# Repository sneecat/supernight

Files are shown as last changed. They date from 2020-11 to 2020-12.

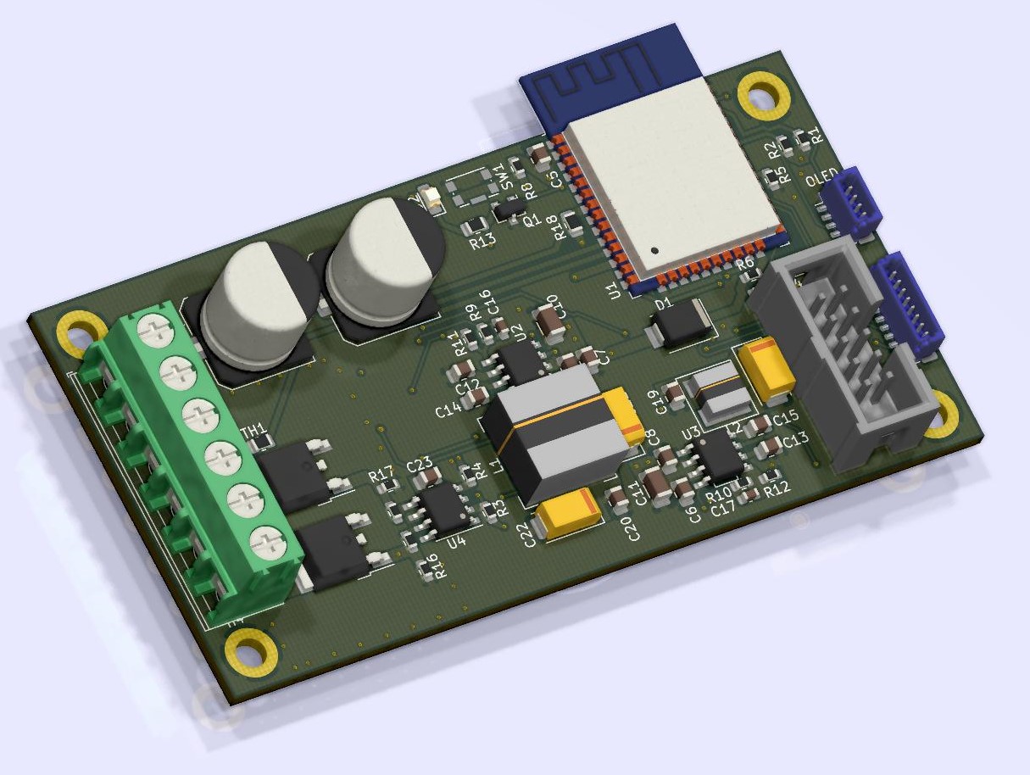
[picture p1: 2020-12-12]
Documentation/supernight2V_0_2.jpg

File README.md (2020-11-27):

# Supernight
Supernight is a series of wifi LED controllers with the following features:

- High current capability (8A per-channel)
- 10 bit dimming
- 25kHz+ PWM for flicker-free film operation
- Lo-Mode 1kHz PWM for higher contrast ratio
- Physical controls
- Manual override
- ArtNet compatible (lumenair, etc.)

This is a work in progress. Currently I am going into software development, to ensure that my PCB is sound before ordering.

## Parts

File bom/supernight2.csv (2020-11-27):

Refs | Value | Footprint | Quantity | MFR | MPN | SPR | SPN
SW1 | SW_SPST | Button_Switch_SMD:SW_Push_1P1T-SH_NO_CK_KMR2xxG | 1 | C&K | KMR231GLFS | digi | 401-1429-1-ND
C1;C2;C3 | 330uF | Capacitor_SMD:CP_Elec_10x10.5 | 3 | panasonic | EEE-FC1V331P | digi | PCE4029CT-ND
C16 | 10pF | Capacitor_SMD:C_0603_1608Metric | 1 | yageo | CC0603JRNPO9BN100 | digi | 311-1058-1-ND
C17 | 5pF | Capacitor_SMD:C_0603_1608Metric | 1 | yageo | CC0603CRNPO9BN5R0 | digi | 311-1054-1-ND
C19;C20;C15;C14;C8;C6;C9;C7 | 100nF | Capacitor_SMD:C_0805_2012Metric | 8 | yageo | CC0805KRX7R7BB104 | digi | 311-1142-1-ND
C5;C13;C12;C23 | 1uF | Capacitor_SMD:C_0805_2012Metric | 4 | yageo | CC0805KKX7R8BB105 | digi | 311-1456-1-ND
C4;C11;C10 | 10uF | Capacitor_SMD:C_1206_3216Metric | 3 | avx | 1206YD106KAT2A | digi | 478-1573-1-ND
C18;C21;C22 | 47uF | Capacitor_Tantalum_SMD:CP_EIA-6032-28_Kemet-C | 3 | vishay | TMCHC1C476MTRF | digi | 718-2350-2-ND
OLED1 | OLED Connector | Connector_JST:JST_SH_BM04B-SRSS-TB_1x04-1MP_P1.00mm_Vertical | 1 | jst | BM04B-SRSS-TB(LF)(SN) | digi | 455-1790-1-ND
J2 | Conn_02x04_Odd_Even | Connector_JST:JST_SH_BM08B-SRSS-TB_1x08-1MP_P1.00mm_Vertical | 1 | jst | SM08B-SRSS-TB(LF)(SN) | digi | 455-1808-1-ND
J1;J5 | 43045-0421 | Connector_Molex:Molex_Micro-Fit_3.0_43045-0421_2x02-1MP_P3.00mm_Horizontal | 2 | molex | 43045-0421 | digi | WM2673-ND
JTAG1 | HTST-105-01-T-DV | Connector_Samtec_HLE_THT:Samtec_HLE-105-02-xx-DV-TE_2x05_P2.54mm_Horizontal | 1 | samtec | HTST-105-01-T-DV | digi | SAM9518-ND
D1 | D | Diode_SMD:D_SMB | 1 | SMC Diode Solutions | SK26TR | digi | 1655-1588-1-ND
L1 | 22uH | Inductor_SMD:L_Bourns-SRN1060 | 1 | bourns | SRN1060-220M | digi | SRN1060-220MCT-ND
L2 | 8.2uH | Inductor_SMD:L_Bourns_PM42S | 1 | - | - | -digi | -
D2 | LED | LED_SMD:LED_0805_2012Metric_Castellated | 1 | osram | LH R974-LP-1 | digi | 475-1415-1-ND
U4 | EL7202CN | Package_SO:SOIC-8_3.9x4.9mm_P1.27mm | 1 | renesas | EL7202CSZ | digi | EL7202CSZ-ND
Q1 | BC847C | Package_TO_SOT_SMD:SOT-23 | 1 | - | - | - | -
Q2;Q3 | DMN3010LK3 | Package_TO_SOT_SMD:TO-252-2 | 2 | diodes incorperated | DMN3010LK3-13 | digi | DMN3010LK3-13-ND
U1 | ESP32 | RF_Module:ESP32-WROOM-32 | 1 | espressif | ESP32-S2-WROOM-I | digi | 1965-ESP32-S2-WROOM-ICT-ND
R7 | 1.4K | Resistor_SMD:R_0603_1608Metric | 1 | Stackpole Electronics Inc | RMCF0603FT1K40 | digi | 738-RMCF0603FT1K40CT-ND
R5;R10;R9;R16;R17 | 100K | Resistor_SMD:R_0603_1608Metric | 5 | TE | CRGCQ0603J100K | digi | A130103CT-ND
R6;R8 | 10K | Resistor_SMD:R_0603_1608Metric | 2 | TE | CRGP0603F10K | digi | A130428CT-ND
R3;R4;R14;R15 | 1K | Resistor_SMD:R_0603_1608Metric | 4 | TE | CRGP0603F1K0 | digi | A130416CT-ND
R2;R1 | 4.7K | Resistor_SMD:R_0603_1608Metric | 2 | yageo | RC0603FR-074K7L | digi | 311-4.70KHRCT-ND
R12 | 43.2K | Resistor_SMD:R_0603_1608Metric | 1 | yageo | RC0603FR-0743K2L | digi | 311-43.2KHRCT-ND
R11 | 9.09K | Resistor_SMD:R_0603_1608Metric | 1 | Stackpole Electronics Inc | RNCP0603FTD9K09 | digi | RNCP0603FTD9K09CT-ND
TH1;R18 | 10K | Resistor_SMD:R_0805_2012Metric | 2 | Stackpole Electronics Inc | RNCP0805FTD10K0 | digi | RNCP0805FTD10K0CT-ND
R13 | 33R | Resistor_SMD:R_0805_2012Metric | 1 | yageo | RT0805FRE0733RL | digi | 13-RT0805FRE0733RLCT-ND
U3 | LMR33610ADDA | SOIC:PowerPad-SOIC-8 | 1 | ti | LMR33610ADDAR | digi | 296-LMR33610ADDARCT-ND
U2 | LMR33640ADDA | SOIC:PowerPad-SOIC-8 | 1 | ti | LMR33640ADDAR | digi | 296-LMR33640ADDARCT-ND
12v_PWGD1 | 12v_PWGD | TestPoint:TestPoint_Pad_D1.5mm | 1 | - | - | - | -
12V_SW1 | 12v_SW | TestPoint:TestPoint_Pad_D1.5mm | 1 | - | - | - | -
3V3_PWGD1 | 3v3_PWGD | TestPoint:TestPoint_Pad_D1.5mm | 1 | - | - | - | -
3V3_SW1 | 3v3_SW | TestPoint:TestPoint_Pad_D1.5mm | 1 | - | - | - | -
TP8 | CH1_FET_D | TestPoint:TestPoint_Pad_D1.5mm | 1 | - | - | - | -
TP7 | CH1_FET_G | TestPoint:TestPoint_Pad_D1.5mm | 1 | - | - | - | -
TP9 | CH1_FET_SIG | TestPoint:TestPoint_Pad_D1.5mm | 1 | - | - | - | -
TP6 | FET_DRV_VIN | TestPoint:TestPoint_Pad_D1.5mm | 1 | - | - | - | -
ESP_TX1 | TX | TestPoint:TestPoint_Pad_D1.5mm | 1 | - | - | - | -
TP1 | VIN | TestPoint:TestPoint_Pad_D1.5mm | 1 | - | - | - | -

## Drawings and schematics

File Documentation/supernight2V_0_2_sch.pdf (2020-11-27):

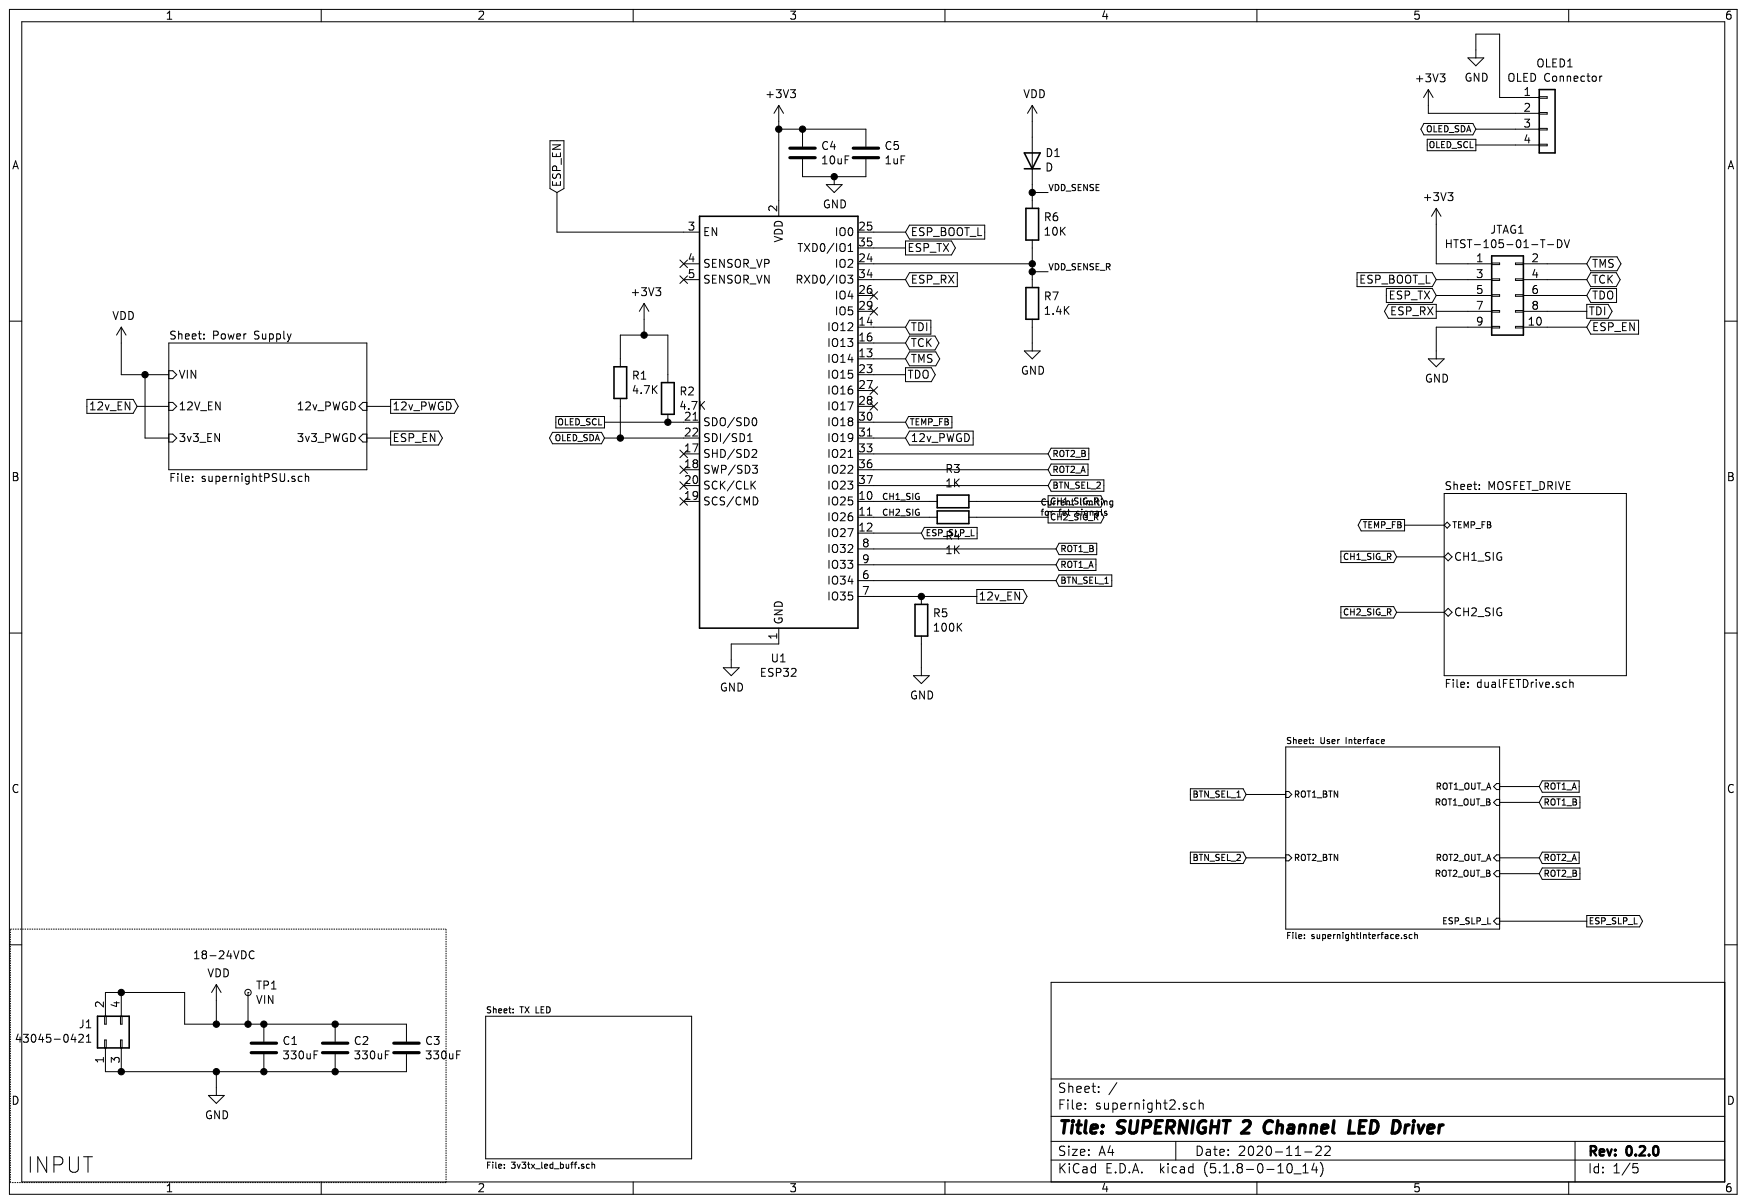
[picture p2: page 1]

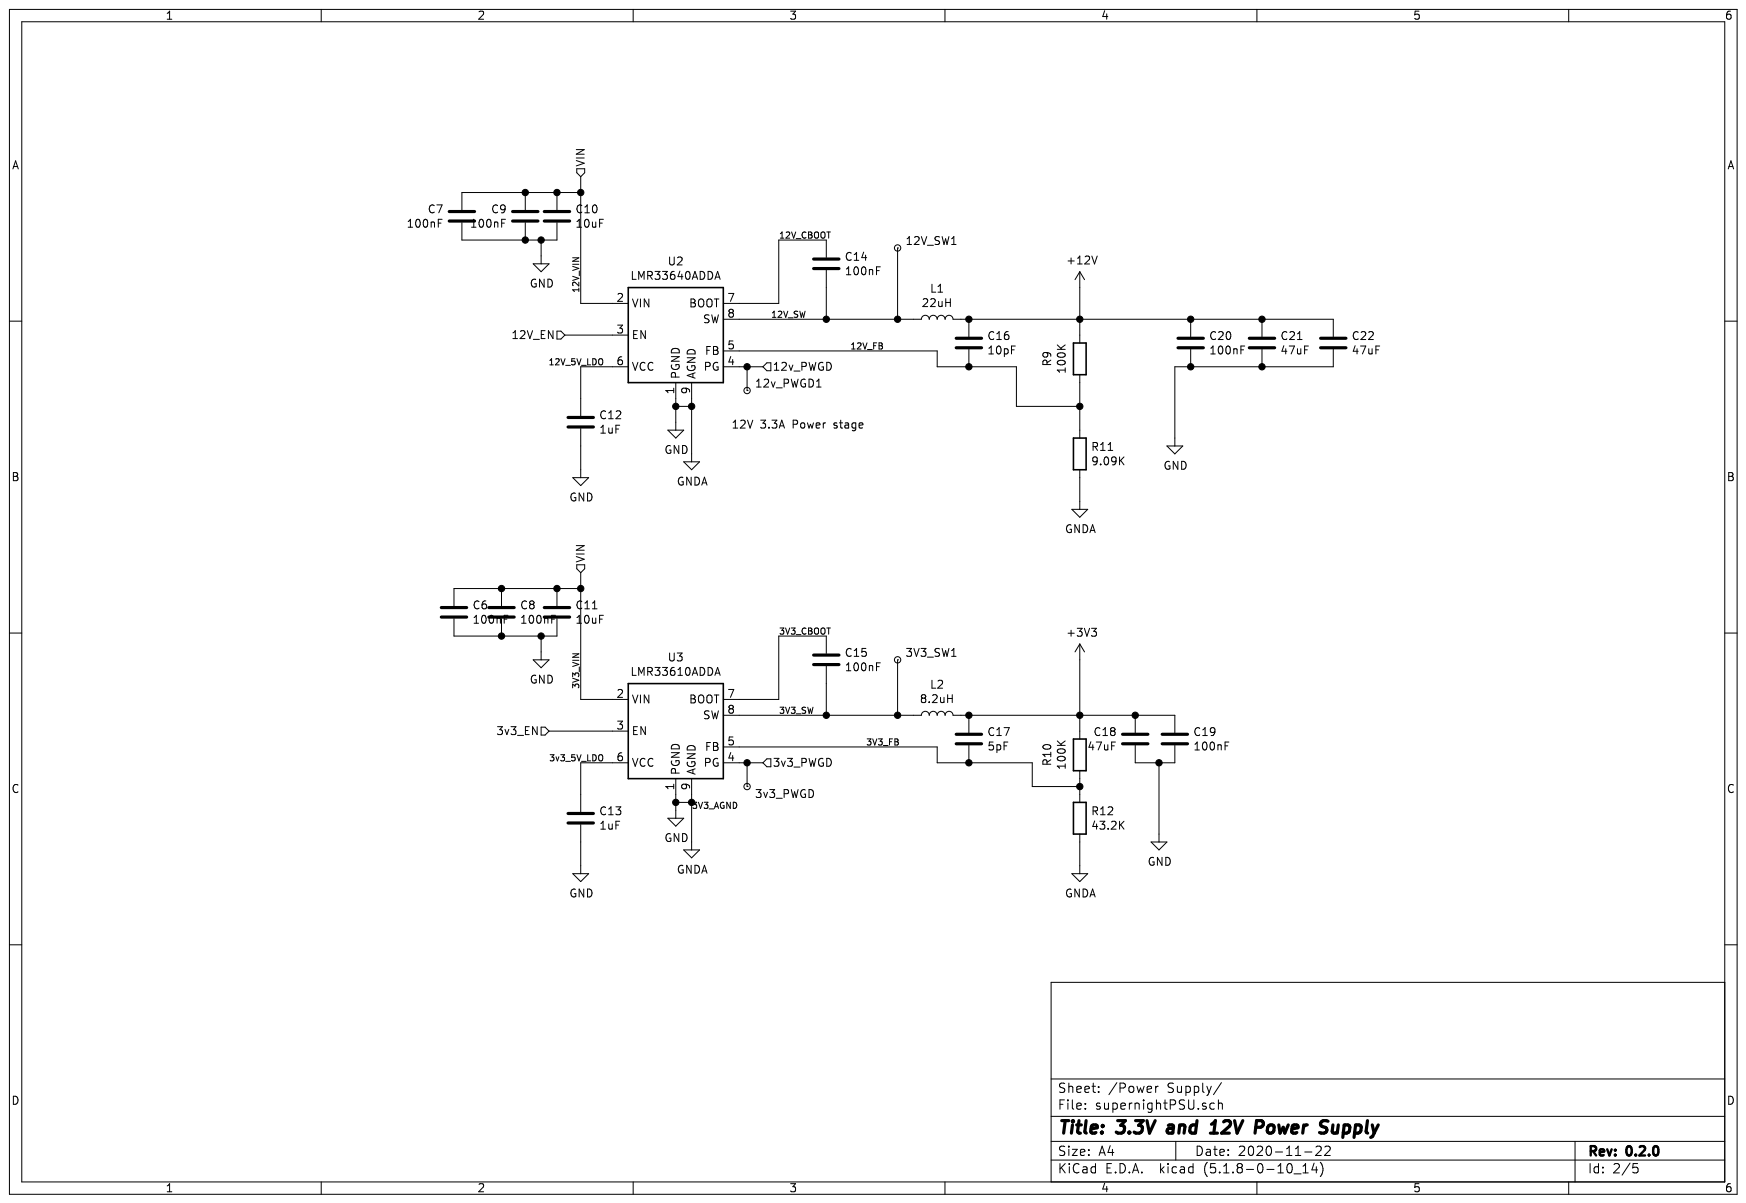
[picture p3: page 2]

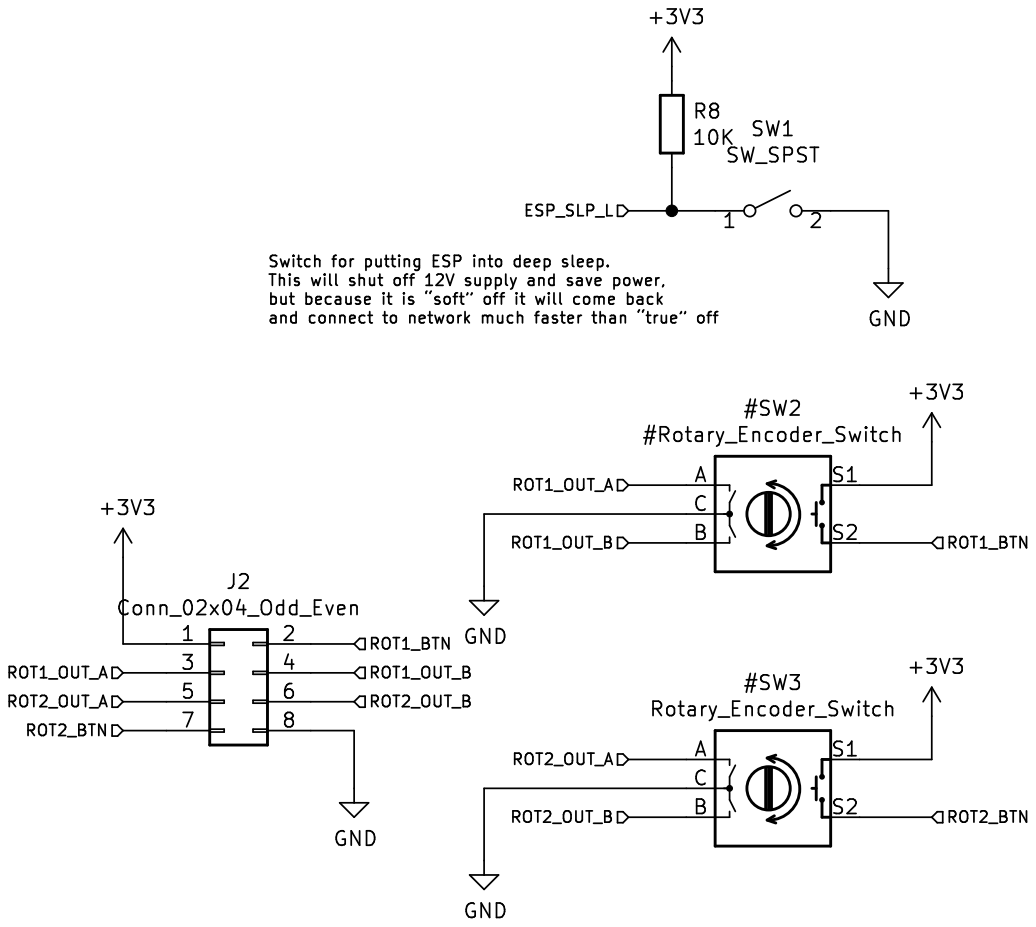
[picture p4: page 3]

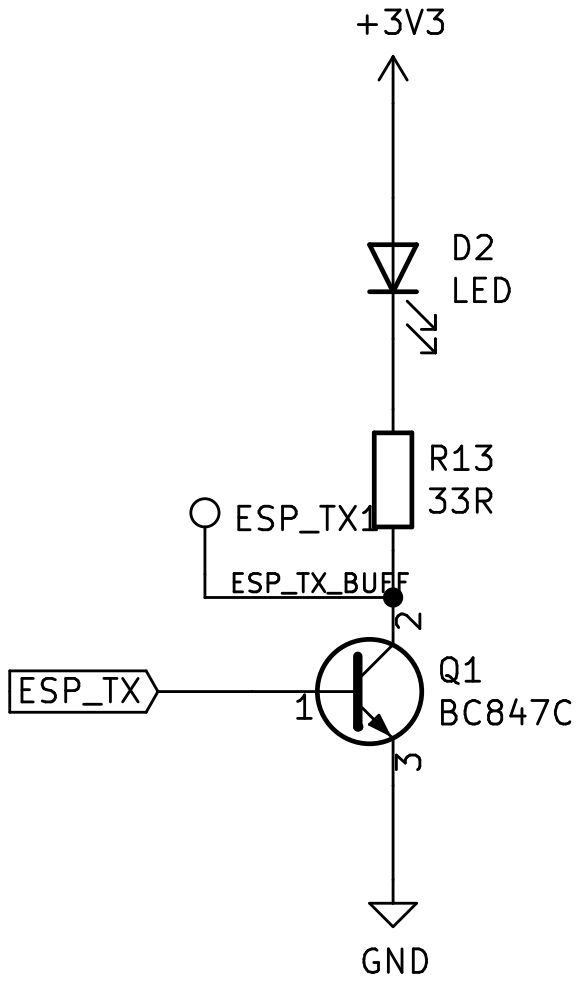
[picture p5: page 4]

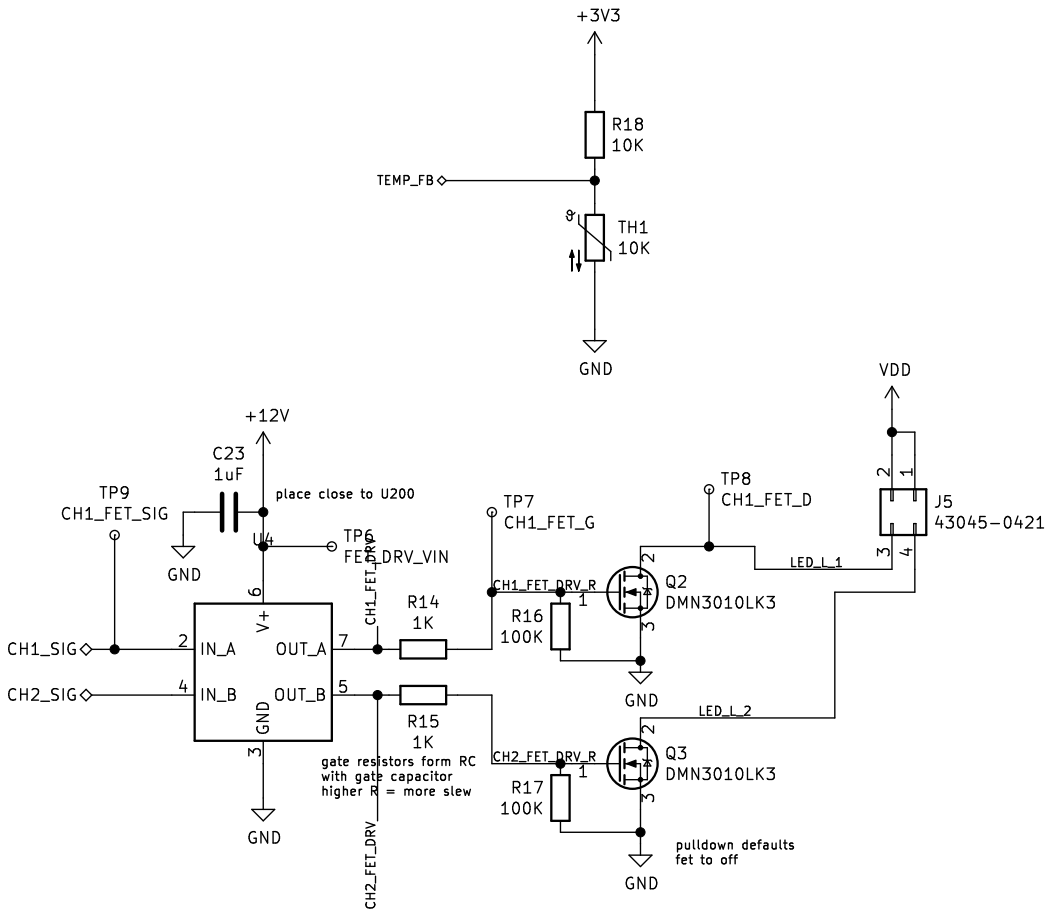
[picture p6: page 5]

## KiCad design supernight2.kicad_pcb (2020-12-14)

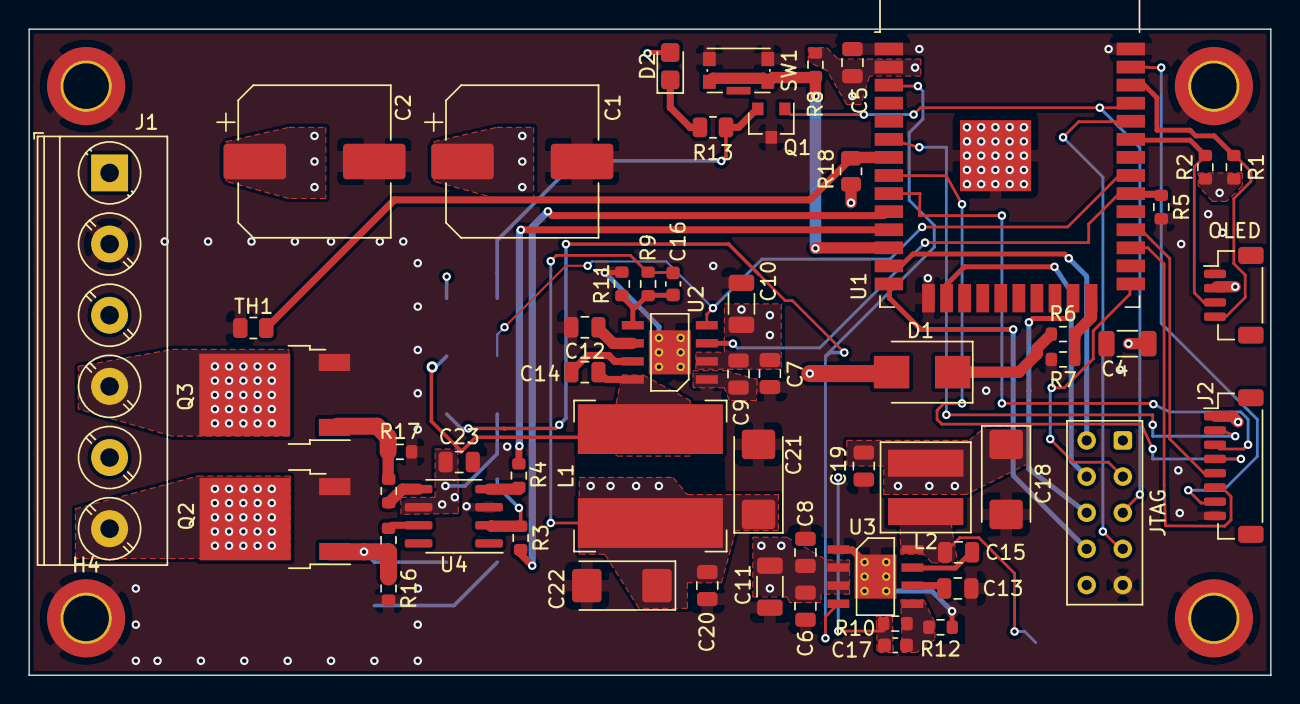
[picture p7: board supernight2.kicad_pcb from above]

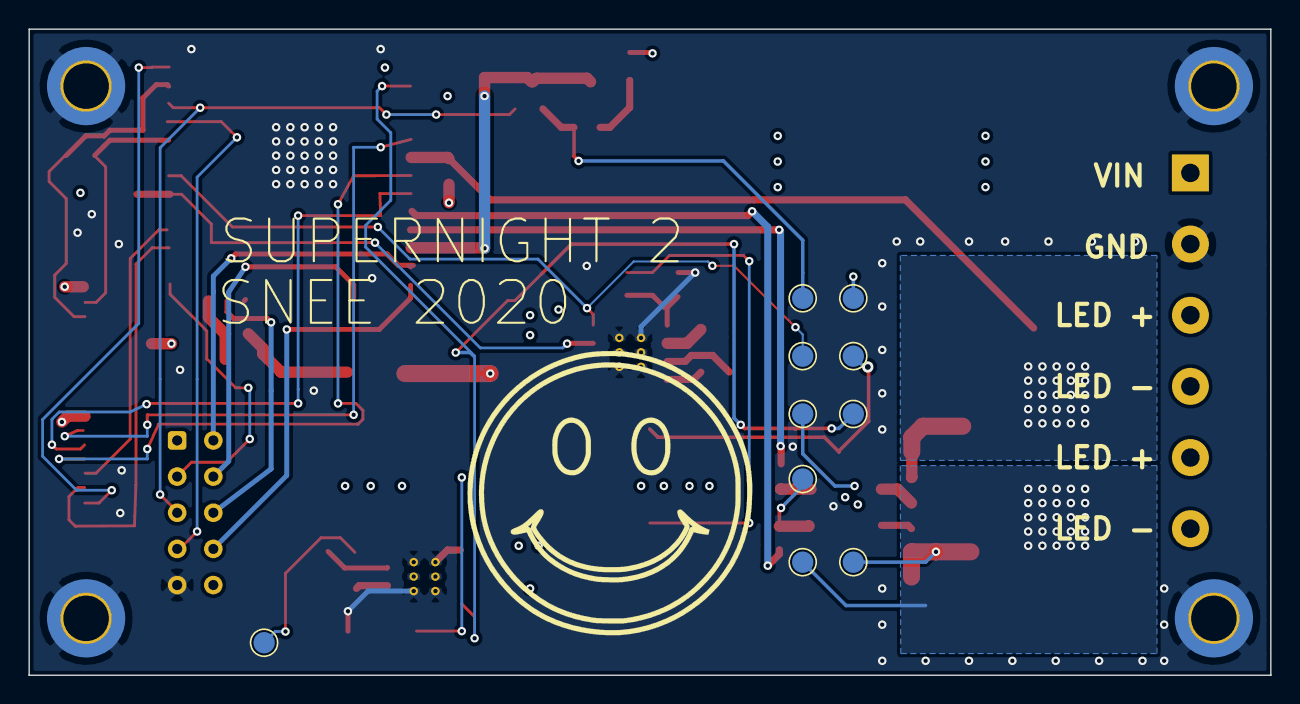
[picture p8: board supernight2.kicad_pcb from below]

Board: 4 copper layers, 87.2 x 45.4 mm, 72 parts (10 on the bottom side), 46 nets.

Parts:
3V3_PWGD1: 3v3_PWGD; TestPoint_Pad_D1.5mm
3V3_SW1: 3v3_SW; TestPoint_Pad_D1.5mm
12V_SW1: 12v_SW; TestPoint_Pad_D1.5mm
12v_PWGD1: 12v_PWGD; TestPoint_Pad_D1.5mm
C1, C2: 330uF; CP_Elec_10x10.5
C4, C10, C11: 10uF; C_1206_3216Metric
C5, C12, C13, C23: 1uF; C_0805_2012Metric
C6, C7, C8, C9, C14, C15, C19, C20: 100nF; C_0805_2012Metric
C16: 10pF; C_0603_1608Metric
C17: 5pF; C_0603_1608Metric
C18, C21, C22: 47uF; CP_EIA-6032-28_Kemet-C
D1: D; D_SMB
D2: LED; LED_0805_2012Metric_Castellated
ESP_TX1: TX; TestPoint_Pad_D1.5mm
H1, H2, H3, H4: MountingHole_Pad; MountingHole_3.2mm_M3_ISO14580_Pad_TopBottom
J1: Conn_01x06_Female; TerminalBlock_Phoenix_PT-1,5-6-5.0-H_1x06_P5.00mm_Horizontal
J2: Conn_02x04_Odd_Even; JST_SH_BM08B-SRSS-TB_1x08-1MP_P1.00mm_Vertical
JTAG: HTST-105-01-T-DV; Samtec_HLE-105-02-xx-DV-TE_2x05_P2.54mm_Horizontal
L1: 22uH; L_Bourns-SRN1060
L2: 8.2uH; L_Bourns_PM42S
OLED: OLED Connector; JST_SH_BM04B-SRSS-TB_1x04-1MP_P1.00mm_Vertical
Q1: BC847C; SOT-23
Q2, Q3: DMN3010LK3; TO-252-2
R1, R2: 4.7K; R_0603_1608Metric
R3, R4, R14, R15: 1K; R_0603_1608Metric
R5, R9, R10, R16, R17: 100K; R_0603_1608Metric
R6, R8: 10K; R_0603_1608Metric
R7: 1.4K; R_0603_1608Metric
R11: 9.09K; R_0603_1608Metric
R12: 43.2K; R_0603_1608Metric
R13: 33R; R_0805_2012Metric
R18: 10K; R_0805_2012Metric
Ref**: Val**; smile
SW1: SW_SPST; SW_Push_1P1T-SH_NO_CK_KMR2xxG
TH1: 10K; R_0805_2012Metric
TP1: VIN; TestPoint_Pad_D1.5mm
TP6: FET_DRV_VIN; TestPoint_Pad_D1.5mm
TP7: CH1_FET_G; TestPoint_Pad_D1.5mm
TP8: CH1_FET_D; TestPoint_Pad_D1.5mm
TP9: CH1_FET_SIG; TestPoint_Pad_D1.5mm
U1: ESP32; ESP32-WROOM-32
U2: LMR33640ADDA; PowerPad-SOIC-8
U3: LMR33610ADDA; PowerPad-SOIC-8
U4: EL7202CN; SOIC-8_3.9x4.9mm_P1.27mm

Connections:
3V3_PWGD: 3V3_PWGD1.1, U1.3, U3.4
12v_EN: R5.1, U1.30, U2.3
12v_PWGD: 12v_PWGD1.1, U1.31, U2.4
+3V3: C4.1, C5.1, C17.1, C18.1, C19.1, D2.2, J2.1, JTAG.1, L2.2, OLED.2, R1.1, R2.1, R8.1, R10.1, R18.1, U1.2
+12V: C16.1, C20.1, C21.1, C22.1, C23.2, L1.2, R9.1, TP6.1, U4.6
/CH1_SIG: R3.2, U1.10
/CH2_SIG: R4.2, U1.11
/MOSFET_DRIVE/CH1_FET_DRV: R14.2, U4.7
/MOSFET_DRIVE/CH1_FET_DRV_R: Q2.1, R14.1, R16.1, TP7.1
/MOSFET_DRIVE/CH2_FET_DRV: R15.2, U4.5
/MOSFET_DRIVE/CH2_FET_DRV_R: Q3.1, R15.1, R17.1
/MOSFET_DRIVE/LED_L_1: J1.6, Q2.2, TP8.1
/MOSFET_DRIVE/LED_L_2: J1.4, Q3.2
/Power Supply/3V3_CBOOT: C15.1, U3.7
/Power Supply/3V3_FB: C17.2, R10.2, R12.1, U3.5
/Power Supply/3V3_SW: 3V3_SW1.1, C15.2, L2.1, U3.8
/Power Supply/3v3_5V_LDO: C13.1, U3.6
/Power Supply/12V_5V_LDO: C12.1, U2.6
/Power Supply/12V_CBOOT: C14.1, U2.7
/Power Supply/12V_FB: C16.2, R9.2, R11.1, U2.5
/Power Supply/12V_SW: 12V_SW1.1, C14.2, L1.1, U2.8
/TX LED/ESP_TX_BUFF: ESP_TX1.1, Q1.2, R13.2
/VDD_SENSE: D1.1, R6.1
/VDD_SENSE_R: R6.2, R7.1, U1.24
BTN_SEL_1: J2.2, U1.6
BTN_SEL_2: J2.7, U1.37
CH1_SIG_R: R3.1, TP9.1, U4.2
CH2_SIG_R: R4.1, U4.4
ESP_BOOT_L: JTAG.3, U1.25
ESP_RX: JTAG.7, U1.34
ESP_SLP_L: R8.2, SW1.1, U1.12
ESP_TX: JTAG.5, Q1.1, U1.35
GND: C1.2, C2.2, C4.2, C5.2, C6.2, C7.2, C8.2, C9.2, C10.2, C11.2, C12.2, C13.2, C18.2, C19.2, C20.2, C21.2, C22.2, C23.1, H1.1, H2.1, H3.1, H4.1, J1.2, J2.8, JTAG.9, OLED.1, Q1.3, Q2.3, Q3.3, R5.2, R7.2, R11.2, R12.2, R16.2, R17.2, SW1.2, TH1.2, U1.1, U1.15, U1.38, U1.39, U2.1, U2.9, U3.1, U3.9, U4.3
unnamed: D2.1, R13.1
OLED_SCL: OLED.4, R1.2, U1.36
OLED_SDA: OLED.3, R2.2, U1.33
ROT1_A: J2.3, U1.9
ROT1_B: J2.4, U1.8
ROT2_A: J2.5, U1.28
ROT2_B: J2.6, U1.27
TCK: JTAG.4, U1.16
TDI: JTAG.8, U1.14
TDO: JTAG.6, U1.23
TEMP_FB: R18.2, TH1.1, U1.7
TMS: JTAG.2, U1.13
VDD: C1.1, C2.1, C6.1, C7.1, C8.1, C9.1, C10.1, C11.1, D1.2, J1.1, J1.3, J1.5, TP1.1, U2.2, U3.2, U3.3

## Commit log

2020-11-18 added fets and driver
    [supernight2.sch]
2020-11-19 test opamp please ignore
    [supernight2.sch]
2020-11-19 added better psu
    [supernight2.sch]
2020-11-19 added sheet schematics
    [dualFETDrive.sch, supernightInterface.sch, supernightPSU.sch]
2020-11-19 part consolidation
    [dualFETDrive.sch, supernight2.sch, supernightInterface.sch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]
2020-11-19 volt sense and encoders
    [dualFETDrive.sch, supernight2.sch, supernightInterface.sch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]
2020-11-25 started pcb
    [3v3tx_led_buff.sch, dualFETDrive.sch, supernight2.kicad_pcb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]
2020-11-25 first layout pass finished
    [3v3tx_led_buff.sch, dualFETDrive.sch, supernight2.kicad_pcb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]
2020-11-27 soft release v0.2
    [3v3tx_led_buff.sch, dualFETDrive.sch, supernight2.csv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]
2020-11-27 file organization
    [supernight2.csv]
2020-11-27 file org
    [supernight2.csv]
2020-11-28 rearranged pcb
    [supernight2.kicad_pcb]
2020-11-28 shrunk pcb somewhat
    [supernight2.kicad_pcb]
2020-11-28 changed fets due to avail/price
    [dualFETDrive.sch]
2020-12-06 changed connector locations
    [supernight2.kicad_pcb]
2020-12-06 ran most of the power
    [supernight2.kicad_pcb, supernight2.sch]
2020-12-07 corrected esp32 pins and buck layout
    [supernight2.kicad_pcb]
2020-12-08 re-linked refs from brd to sch
    [dualFETDrive.sch, supernight2.kicad_pcb, supernight2.sch]
2020-12-08 adding therm vias and silk markings
    [supernight2.kicad_pcb]
2020-12-09 added via fence and testpoints
    [supernight2.kicad_pcb]
2020-12-12 finished re-layout
    [supernight2.sch]
2020-12-12 fixing refs, thermal pads, mosfet thermals
    [3v3tx_led_buff.sch, dualFETDrive.sch, supernight2.kicad_pcb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]
2020-12-12 removed git head from file
    [supernight2.kicad_pcb]
2020-12-12 final checks, adding 3d models
    [supernight2.kicad_pcb]
2020-12-14 BOM prep
    [dualFETDrive.sch, supernight2.kicad_pcb]
